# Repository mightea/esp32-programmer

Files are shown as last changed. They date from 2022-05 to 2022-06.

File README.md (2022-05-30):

# esp32-programmer

<p style="background-color:yellow">
<font color="black"> ⚠️  Work in progress...</font>
</p>

Serial programmer for ESP32 and ESP8266 boards designed with [KiCad EDA](https://www.kicad.org/).
The programmer has the following features:

- TC2030-IDC connector
- USB-C connector
- 3.3v Power Switch (for connecting to serial console with external board power)
- Onboard RX/TX status LED's

## Project Status

- [ ] Design basic PCB layout
- [ ] Generate fabrication data
- [ ] Fabicate prototypes
- [ ] Test prototype

esp32-programmer

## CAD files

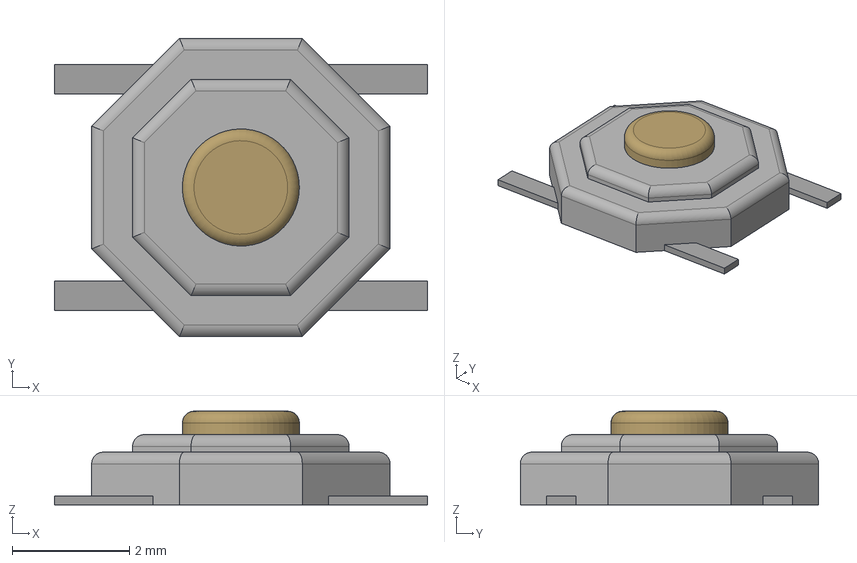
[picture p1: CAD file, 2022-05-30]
pcb/3dmodels/TS-1187A-B-A-B.step
6.38 x 5.10 x 1.60 mm

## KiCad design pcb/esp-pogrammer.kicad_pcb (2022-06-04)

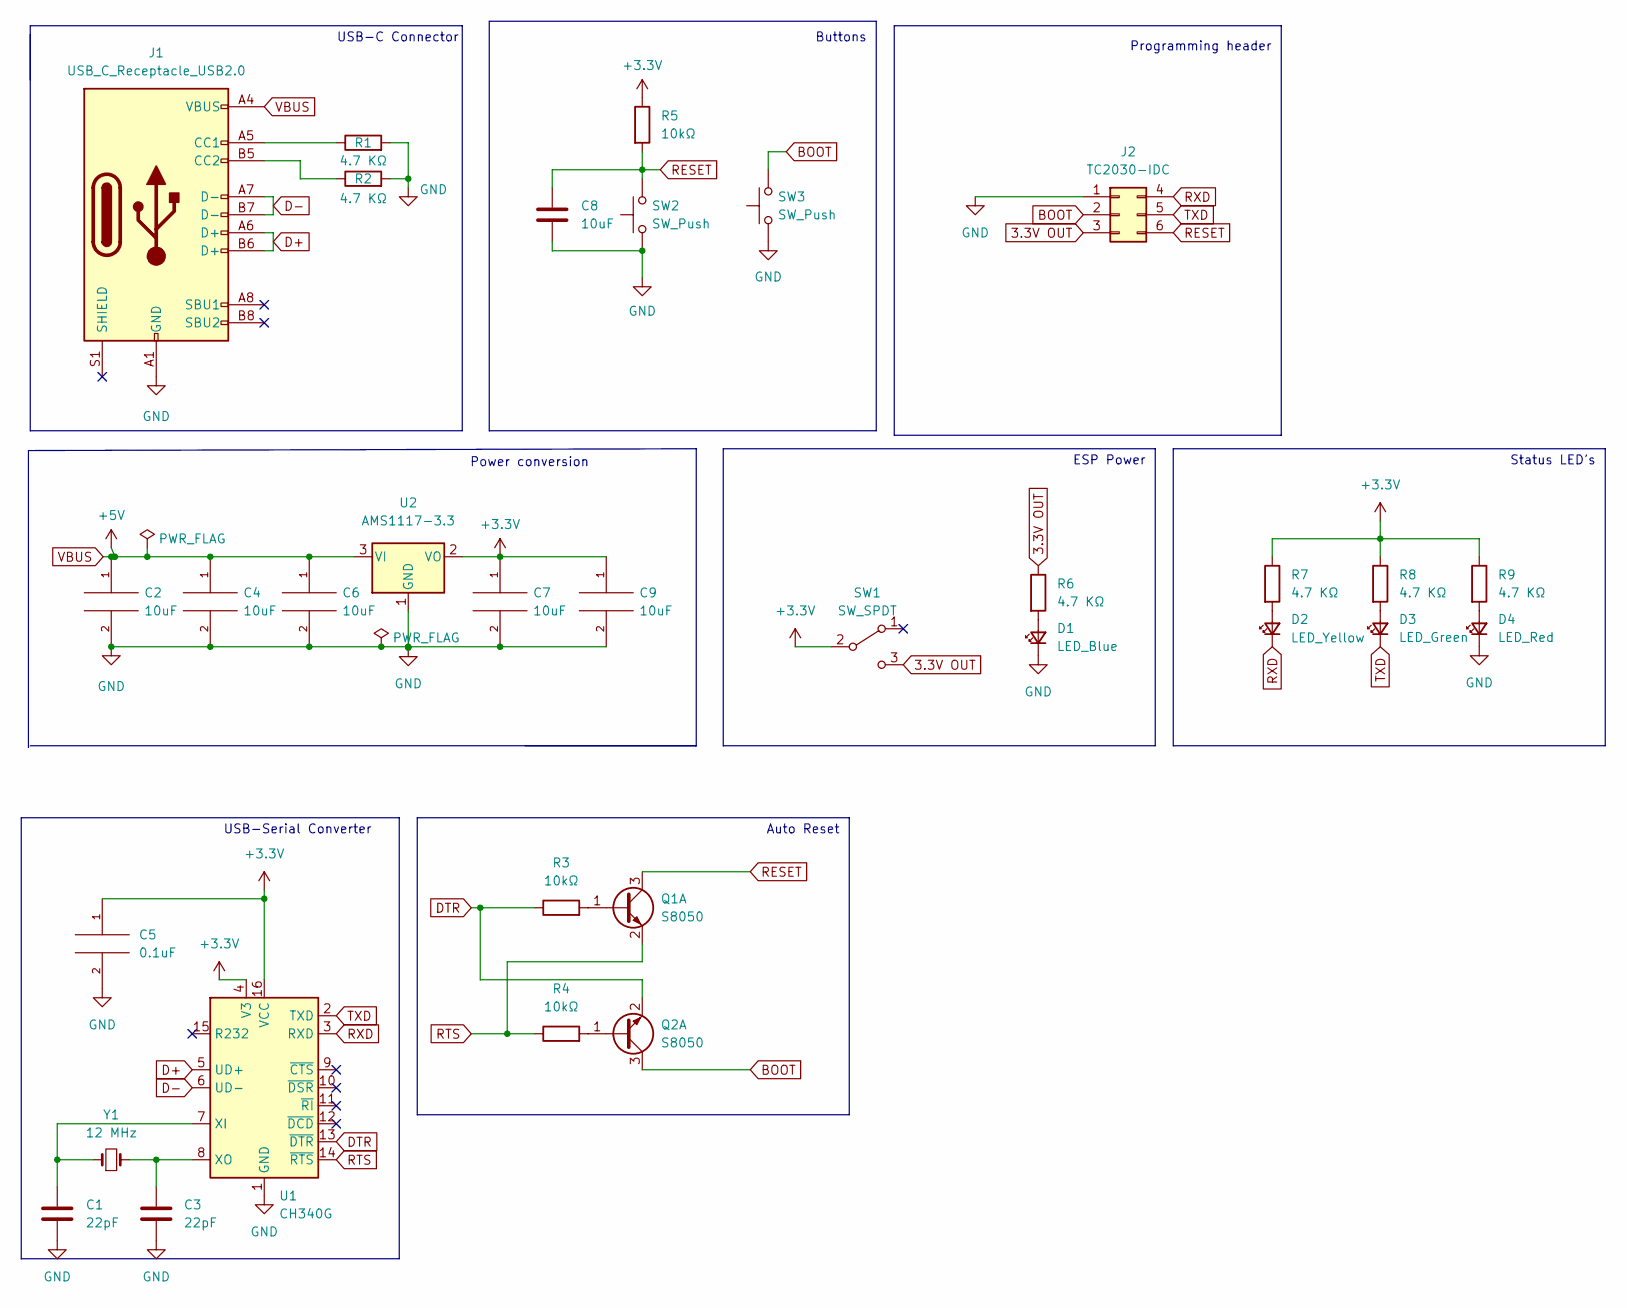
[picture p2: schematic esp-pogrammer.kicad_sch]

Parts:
C1, C3: 22pF; C_0603_1608Metric
C2, C4, C6, C7, C8, C9: 10uF; C_0603_1608Metric
C5: 0.1uF; C_0603_1608Metric
D1: LED_Blue; LED_0603_1608Metric
D2: LED_Yellow; LED_0603_1608Metric
D3: LED_Green; LED_0603_1608Metric
D4: LED_Red; LED_0603_1608Metric
J1: USB_C_Receptacle_USB2.0; USB_C_Receptacle_HRO_TYPE-C-31-M-12
J2: TC2030-IDC; IDC-Header_2x03_P2.54mm_Vertical
Q1, Q2: S8050; SOT-23
R1, R2: 4.7 KΩ; R_0603_1608Metric
R3, R4, R5: 10kΩ; R_0603_1608Metric
R6, R7, R8, R9: 4.7 KΩ; R_0603_1608Metric; jlcpcb C25905
SW1: SW_SPDT; SW_CuK_JS202011AQN_DPDT_Angled
SW2, SW3: SW_Push; TS-1187A-B-A-B
U1: CH340G; SOIC-16_3.9x9.9mm_P1.27mm
U2: AMS1117-3.3; SOT-223-3_TabPin2
Y1: 12 MHz; Crystal_SMD_0603-2Pin_6.0x3.5mm

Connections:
3.3V OUT: J2.3, R6.1, SW1.3 (C)
+3V3: C5.1, C7.1, C9.1, R5.1, R7.1, R8.1, R9.1, SW1.2 (B), U1.4 (V3), U1.16 (VCC), U2.2 (VO)
BOOT: J2.2, Q2.3 (C3), SW3.2
D+: J1.A6 (D+), J1.B6 (D+), U1.5 (UD+)
D-: J1.A7 (D-), J1.B7 (D-), U1.6 (UD-)
DTR: Q2.2 (E2), R3.1, U1.13 (~DTR)
GND: C1.2, C2.2, C3.2, C4.2, C5.2, C6.2, C7.2, C8.2, C9.2, D1.1 (K), D4.1 (K), J1.A1 (GND), J1.A12 (GND), J1.B1 (GND), J1.B12 (GND), J2.1, R1.2, R2.2, SW2.1, SW3.1, U1.1 (GND), U2.1 (GND)
unnamed: C1.1, U1.7 (XI), Y1.1
unnamed: C3.1, U1.8 (XO), Y1.2
unnamed: D1.2 (A), R6.2
unnamed: D2.2 (A), R7.2
unnamed: D3.2 (A), R8.2
unnamed: D4.2 (A), R9.2
unnamed: J1.A5 (CC1), R1.1
unnamed: J1.B5 (CC2), R2.1
unnamed: Q1.1 (B1), R3.2
unnamed: Q2.1 (B1), R4.2
RESET: C8.1, J2.6, Q1.3 (C3), R5.2, SW2.2
RTS: Q1.2 (E2), R4.1, U1.14 (~RTS)
RXD: D2.1 (K), J2.4, U1.3 (RXD)
TXD: D3.1 (K), J2.5, U1.2 (TXD)
VBUS: C2.1, C4.1, C6.1, J1.A4 (VBUS), J1.A9 (VBUS), J1.B4 (VBUS), J1.B9 (VBUS), U2.3 (VI)

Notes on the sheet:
Status LED's
Programming header
Power conversion
Auto Reset
Buttons
USB-Serial Converter
USB-C Connector
ESP Power

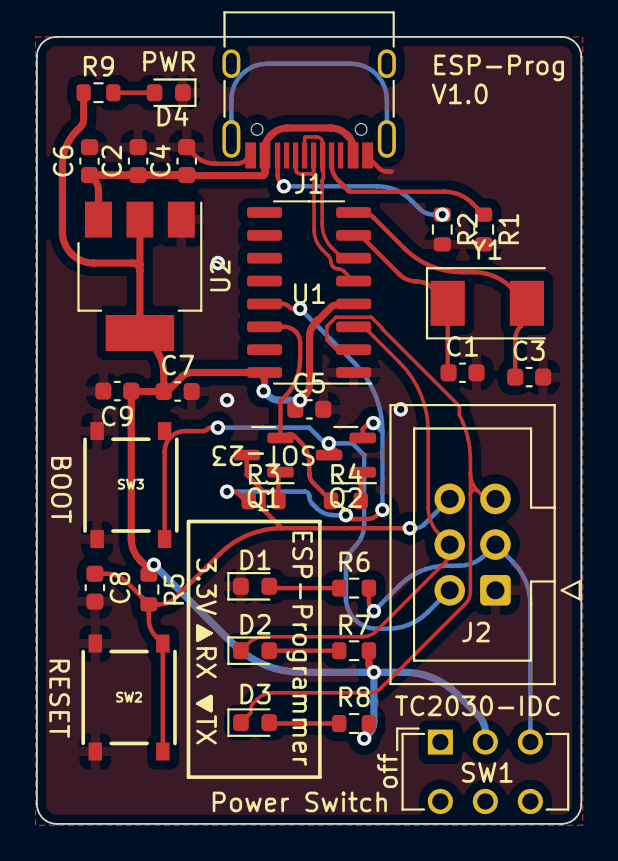
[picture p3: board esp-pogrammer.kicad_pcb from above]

Board: 2 copper layers, 30.2 x 43.7 mm, 32 parts (0 on the bottom side), 22 nets.

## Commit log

2022-05-30 initial import
    [TS-1187A-B-A-B.step, esp-pogrammer.kicad_pcb, esp-pogrammer.kicad_sch]
2022-05-31 updates layout
    [esp-pogrammer.kicad_pcb, esp-pogrammer.kicad_sch]
2022-05-31 added some filter caps, replaced local chip filter, replaced crystal caps, fixed switched power on reset, routed, rounded.
    [esp-pogrammer.kicad_pcb, esp-pogrammer.kicad_sch]
2022-06-04 fixed transistors. minor changes. ordered prototype 0.1.
    [esp-pogrammer.kicad_pcb, esp-pogrammer.kicad_sch]
